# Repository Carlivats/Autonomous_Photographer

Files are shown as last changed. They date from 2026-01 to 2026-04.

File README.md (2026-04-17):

# Autonomous Photographer
*Developed by Carlos Vasquez Trochez | Supervised by Komalpreet Kaur, PhD**

*Salem State University | Computer Science Department**

The Autonomous Photographer is an intelligent, robotic camera system **designed to eliminate the compromises of taking photos during travel, outdoor activities, or public events.** By automatically recognizing subjects, analyzing scene composition, and executing motor movements, it captures visually balanced, professional-quality photographs independently.

**Built for portability and affordability,** the system allows users to step into their environment while the camera evaluates the composition, repositions itself, and takes the perfect shot.

---

## 🚀 Key Features

* **Real-Time AI Vision (YOLOv8):** Deploys OpenCV and lightweight deep learning models (YOLOv8) for continuous subject detection. Tracking logic has been custom-engineered to prioritize facial keypoints (specifically centering on the nose)
* **Autonomous Hardware Reframing:** Evaluates scene layout based on established photographic principles (like the Rule of Thirds or Centered Symmetry). The control system translates composition scores into precise pan-tilt motor commands, actively adjusting the frame in under **2 seconds per iteration**.
* **Quality Assurance Analysis:** Continuously evaluates sharpness, contrast, exposure, and motion blur. The automated rating engine discards blurry or poorly lit shots and retains only high-quality photos.
* **Highly Portable & Wireless:** Equipped with a 5V UPS Shield and batteries for continuous, untethered power. 
* **Intuitive User Interface:** A desktop-class interface built with PyQt5 that mimics an everyday camera app. Users can initiate sessions, adjust framing preferences, check live statistics, and browse the integrated gallery.

---

## 🛠️ Hardware Architecture

The physical build was designed for accessibility and reproducibility using cost-effective components. **All custom 3D-printed chassis files (.stl / LycheeSlicer files) are available in this repository!!**

* **Compute & AI Acceleration:**
  * Raspberry Pi 5
  * Hailo AI HAT+ (handles computationally expensive object-detection models)
* **Vision:**
  * Raspberry Pi AI Camera Module (IMX500)
* **Motion Control:**
  * Custom 3D-printed pan-tilt mount
  * Two precision Servo Motors
  * **PCA9685 Servo Driver:** Isolates motor power from the logic board, resolving voltage-related trembling to ensure smooth, stable camera motion.
* **Power:**
  * UPS 5V Shield + Batteries for field portability

---

## 💻 Software Stack

* **Programming Language:** Python
* **Libraries & Frameworks:** OpenCV, NumPy, PyQt5 (User Interface), RPi.GPIO (Hardware Control)
* **Machine Learning:** YOLOv8
* **3D Modeling & Printing:** Blender, LycheeSlicer
* **Project Management:** Miro, GitHub

---

## 📂 Data Storage Strategy

Captured images are saved directly to local storage alongside corresponding JSON metadata files (using the exact same basename). This sidecar metadata logs:
* Timestamps
* Sharpness & Motion Blur scores
* Exposure & Contrast ratings
* Overall Composition score
* Detected subject coordinates

---

## 🔮 Future Scope

While the current prototype successfully bridges the gap between casual photography and professional composition, future iterations will focus on:
1. **Model Compression:** Optimizing the object-detection models to run entirely on the native Raspberry Pi 5 hardware, removing the need for the Hailo AI HAT+ to further reduce hardware costs.
2. **Mobile Application:** Transitioning the UI to a dedicated mobile application to provide a more accessible wireless connection and control experience for everyday users.

---

## 📬 Contact
**Carlos Vasquez Trochez**
* Email: carlosvasqueztrochez@gmail.com
* GitHub: [Carlivats](https://github.com/Carlivats)

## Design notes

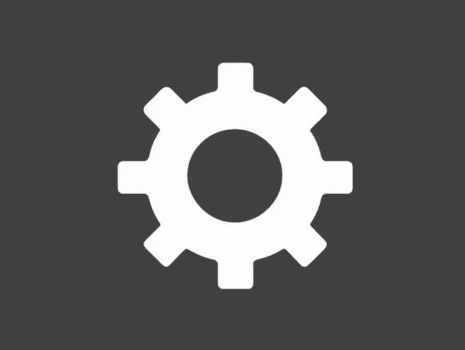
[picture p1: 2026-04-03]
src/assets/gear.png

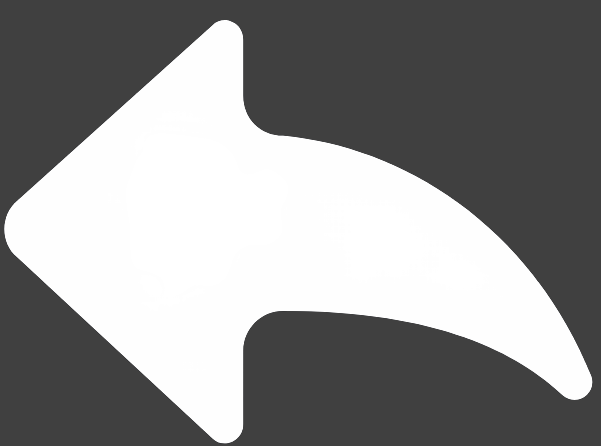
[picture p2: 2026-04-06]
src/assets/back.png

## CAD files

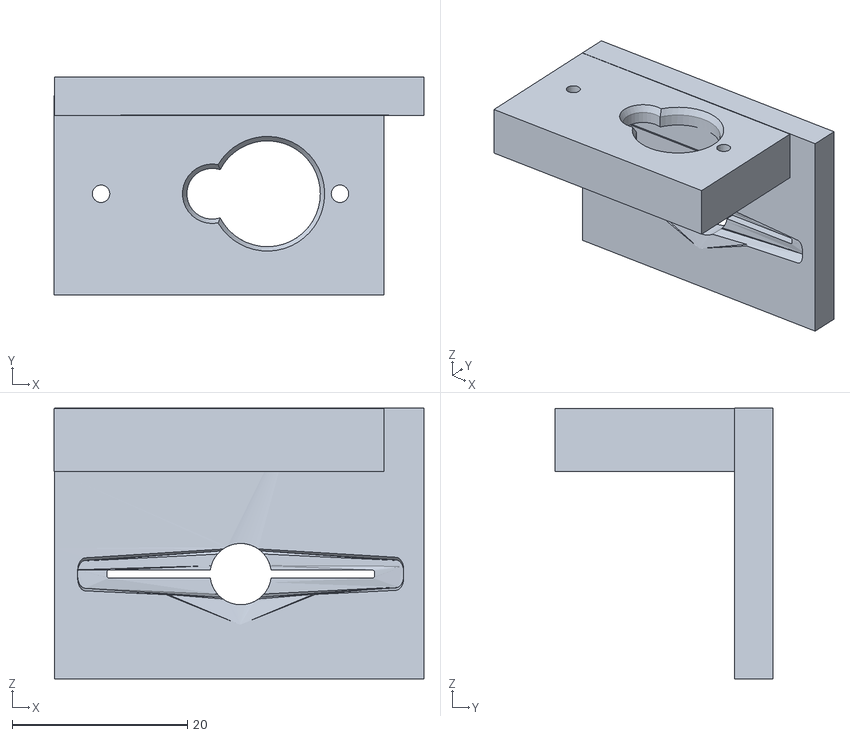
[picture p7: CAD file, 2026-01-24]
hardware/stl/ServoHolder.stl
42.3 x 24.9 x 31.0

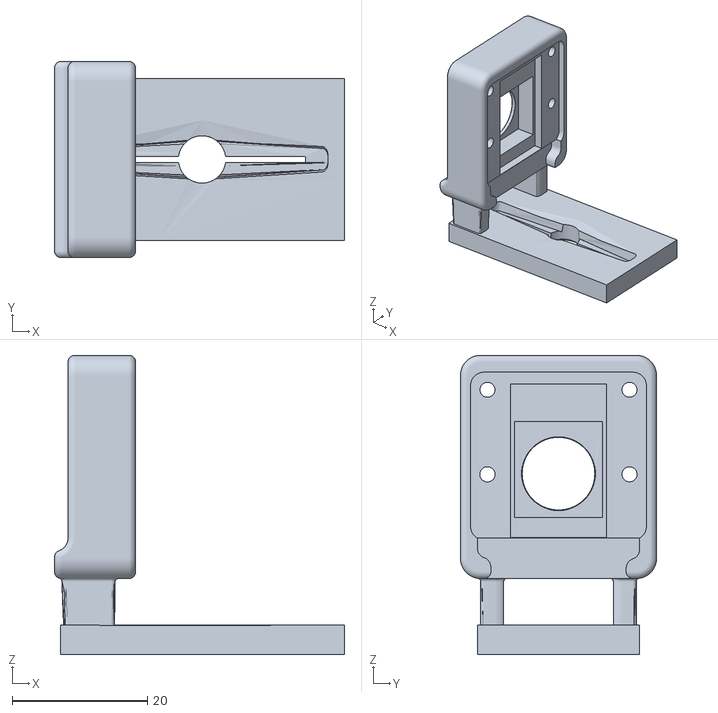
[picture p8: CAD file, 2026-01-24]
hardware/stl/CamaraHolder.stl
42.9 x 29.0 x 44.3

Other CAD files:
hardware/cad/AutonomousPhotographer_v1.00.blend
hardware/cad/AutonomousPhotographer_v1.01.blend
hardware/cad/AutonomousPhotographer_v1.02.blend
hardware/cad/AutonomousPhotographer_v1.03.blend
hardware/cad/AutonomousPhotographer_v1.04.blend

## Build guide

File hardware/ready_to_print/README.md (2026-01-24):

## 3D Printed Parts

The .pwmx files in this directory were used to fabricate prototype components for this project.
If you rather see the STL files you might find them [here](https://github.com/Carlivats/Autonomous_Photographer/tree/main/hardware/stl)

They were printed on the hardware listed below and may require adjustment to work correctly on other printers or setups.

### Printing Environment
- **Printer:** Anycubic Photon Mono X (resin printer)  
- **Resin:** Anycubic Standard Resin V2 (Gray)

### Notes & Disclaimer
- Tolerances, fit, and print quality may vary depending on printer model, resin type, and slicer settings.  
- As this project is still under active development, the designs are **subject to change** and may contain issues.
- These files are provided primarily for reference and prototyping purposes.

Fell free to to modify, re-slice, or redesign parts as needed to suit their own hardware and requirements!

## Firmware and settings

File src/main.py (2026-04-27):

# main.py
import os
import sys
import argparse
from PyQt5.QtWidgets import QApplication, QWidget, QLabel, QPushButton, QVBoxLayout, QHBoxLayout, QSizePolicy
from PyQt5.QtCore import Qt, QSize
from PyQt5.QtGui import QPixmap, QIcon

# Import our custom worker thread
from vision import CameraWorker
from session_manager import CaptureSessionManager
from gallery import GalleryUI
from settings import SettingsUI


class AutonomousPhotographerUI(QWidget):
    def __init__(self, model_path):
        super().__init__()
        self.setWindowTitle("Autonomous Photographer")
        self.resize(1024, 600)
        self.show()
        self.setStyleSheet("background-color: #16181d;")
        home_dir = os.path.expanduser("~")
        self.custom_gallery_folder = os.path.expanduser("~/Pictures/AutonomousPhotographer")

        icon_path = os.path.join(os.path.dirname(__file__), 'assets', 'gear.png')

        main_layout = QHBoxLayout()
        self.setLayout(main_layout)

        # Video Feed
        self.video_label = QLabel(self)
        self.video_label.setAlignment(Qt.AlignCenter)
        self.video_label.setStyleSheet("background-color: black; border: 2px solid #1c2024;")
        self.video_label.setSizePolicy(QSizePolicy.Ignored, QSizePolicy.Ignored)
        self.video_label.setMinimumSize(320, 240)
        main_layout.addWidget(self.video_label, stretch=3)

        # Control Panel
        control_layout = QVBoxLayout()
        
        button_style = """
            QPushButton {
                background-color: #1c2024; color: white;
                font-size: 20px; font-weight: bold;
                padding: 15px; border-radius: 8px;
            }
            QPushButton:pressed { background-color: #525a70; }
        """

        control_layout.addSpacing(20) 
        
        self.btn_settings = QPushButton("", self)
        self.btn_settings.setFixedSize(80, 80)
        
        self.btn_settings.setIcon(QIcon(icon_path))
        
        # Scale the image inside the button (40x40 leaves nice padding inside the 80x80 button)
        self.btn_settings.setIconSize(QSize(75, 75)) 
        
        self.btn_settings.setStyleSheet("""
            QPushButton {
                background-color: #1c2024; 
                border-radius: 40px; 
                border: 2px solid #525a70;
            }
            QPushButton:hover { border: 2px solid white; background-color: #2b3038; }
            QPushButton:pressed { background-color: #525a70; }
        """)
        self.btn_settings.clicked.connect(self.open_settings)

        # Center it horizontally
        settings_layout = QHBoxLayout()
        settings_layout.addStretch()
        settings_layout.addWidget(self.btn_settings)
        settings_layout.addStretch()
        
        control_layout.addLayout(settings_layout)

        self.stats_label = QLabel(self.video_label)

        control_layout.addStretch()
        
        # 1. Define the dynamic styles for the button
        self.btn_idle_style = """
            QPushButton {
                background-color: white; 
                border-radius: 40px;  /* Exactly half the width/height to make a circle */
                border: 4px solid #525a70;
            }
            QPushButton:pressed { background-color: #d0d0d0; }
        """
        
        self.btn_active_style = """
            QPushButton {
                background-color: #e74c3c; /* Red */
                border-radius: 40px;
                border: 4px solid white;
            }
            QPushButton:pressed { background-color: #c0392b; }
        """

        # 2. Create the toggle button
        self.btn_toggle = QPushButton("", self)
        self.btn_toggle.setFixedSize(80, 80)
        self.btn_toggle.setStyleSheet(self.btn_idle_style)
        self.btn_toggle.clicked.connect(self.toggle_session)

        # 3. Center the button horizontally using an internal layout
        btn_layout = QHBoxLayout()
        btn_layout.addStretch()
        btn_layout.addWidget(self.btn_toggle)
        btn_layout.addStretch()

        # Add the centered button to the main control panel
        control_layout.addLayout(btn_layout)
        
        control_layout.addStretch()
        
        # Use RGBA for the background color to set the alpha channel (transparency)
        # 166 out of 255 is roughly 65% opacity (35% transparent)
        self.stats_label.setStyleSheet("""
            background-color: rgba(28, 32, 36, 166); 
            color: #a0aabf; 
            font-size: 16px; 
            font-family: monospace;
            padding: 15px;
            border-radius: 0px;
        """)

        # Initialize with placeholder text
        self.stats_label.setText("Sharpness : N/A\nExposure  : N/A\nContrast  : N/A\nScene Blur: N/A")
        
        # 2. Position it in the top-left corner with a 15px margin
        self.stats_label.move(15, 15)
        
        # 3. Ensure it sizes itself correctly right on startup
        self.stats_label.adjustSize()

        self.btn_gallery = QPushButton("Gallery", self)
        self.btn_gallery.setStyleSheet(button_style)
        self.btn_gallery.clicked.connect(self.open_gallery)
        control_layout.addWidget(self.btn_gallery)

        self.btn_exit = QPushButton("Exit App", self)
        self.btn_exit.setStyleSheet(button_style.replace("#1c2024", "#e74c3c").replace("#525a70", "#c0392b"))
        self.btn_exit.clicked.connect(self.close_app)
        control_layout.addWidget(self.btn_exit)

        main_layout.addLayout(control_layout, stretch=1)

        # --- Initialize Session Manager ---
        self.session_manager = CaptureSessionManager(gallery_dir=self.custom_gallery_folder)
        self.session_manager.session_finished_signal.connect(self.end_session_ui)

        # --- Initialize and Start the Camera Thread ---
        self.thread = CameraWorker(model_path)
        self.thread.change_pixmap_signal.connect(self.update_image)
        self.thread.stats_signal.connect(self.update_stats_panel)
        
        self.thread.start()

    # --- UI Slots (Actions) ---
    def update_image(self, q_img_annotated, q_img_clean):
        # Save the CLEAN frame to memory so the session manager can grab it
        self.current_frame = q_img_clean.copy() 
        
        # Show the ANNOTATED frame with all the tracking lines on the UI screen
        pixmap = QPixmap.fromImage(q_img_annotated)
        scaled_pixmap = pixmap.scaled(self.video_label.size(), Qt.KeepAspectRatio, Qt.SmoothTransformation)
        self.video_label.setPixmap(scaled_pixmap)

    def toggle_session(self):
        """Toggles the autonomous tracking state and updates the button color."""
        if not self.thread.is_tracking:
            # Turn ON
            print("Starting autonomous session...")
            self.thread.is_tracking = True
            self.btn_toggle.setStyleSheet(self.btn_active_style)
            
            self.session_manager.start_session()
        else:
            # Turn OFF Manually
            self.end_session_ui()

    def end_session_ui(self):
        """Resets the UI when a session ends automatically or manually."""
        print("Stopping autonomous session...")
        self.thread.is_tracking = False
        self.session_manager.stop_session()
        self.btn_toggle.setStyleSheet(self.btn_idle_style)

    def update_stats_panel(self, stats):
        """Updates the text label whenever the vision thread emits new data."""
        sharpness = stats.get("sharpness", "N/A")
        exposure = stats.get("exposure", "N/A")
        exposure_status = stats.get("exposure_status", "N/A")
        contrast = stats.get("contrast", "N/A")
        contrast_status = stats.get("contrast_status", "N/A")
        blur = stats.get("blur", "N/A")
        blur_status = stats.get("blur_status", "N/A")
        
        display_text = (
            f"Sharpness : {sharpness}\n"
            f"Exposure  : {exposure} ({exposure_status})\n"
            f"Contrast  : {contrast} ({contrast_status})\n"
            f"Scene Blur: {blur} ({blur_status})"
        )
        self.stats_label.setText(display_text)
        
        # Add this line to force the transparent box to snap to the new text size
        self.stats_label.adjustSize()
        
        if self.thread.is_tracking and hasattr(self, 'current_frame'):
            self.session_manager.process_frame(stats, self.current_frame)

    def open_settings(self):
        print("Opening Settings...")
        # Create an instance of the Settings UI
        self.settings_window = SettingsUI()
        
        # Show the settings window
        self.settings_window.show()

    def open_gallery(self):
        print("Opening Gallery...")
        # Create an instance of the Gallery UI
        self.gallery_window = GalleryUI(gallery_dir=self.custom_gallery_folder)
        
        # Show the gallery window
        self.gallery_window.show()

    def close_app(self):
        self.thread.stop()
        self.close()

if __name__ == "__main__":
    parser = argparse.ArgumentParser()
    parser.add_argument('-m', '--model', default='/usr/share/hailo-models/yolov8s_pose_h8l_pi.hef')
    args = parser.parse_args()

    app = QApplication(sys.argv)
    window = AutonomousPhotographerUI(args.model)
    sys.exit(app.exec_())

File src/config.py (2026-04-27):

# config.py

# Camera & Display Settings
WIDTH = 1024
HEIGHT = 768
FRAME_CX = WIDTH // 2
FRAME_CY = HEIGHT // 2

# Tracking Constants
GAIN_PAN = 0.5
GAIN_TILT = 0.15
DEADZONE = 0.03
STICKINESS = 0.8
CENTER_WIDTH = 0.25

# Vertical position for Centered Symmetry (0.0 to 1.0)
# 0.5 is dead center (lots of headroom). 0.33 is the upper third line (standard portrait).
CENTER_FACE_Y = 0.33 

# X is exactly middle (0.5), Y uses our portrait offset
CENTER_TARGET = (0.5, CENTER_FACE_Y)
INTERSECTIONS = [
    (0.33, 0.33), (0.66, 0.33),
    (0.33, 0.66), (0.66, 0.66)
]

# Servo Channels
PAN_CHANNEL = 1
TILT_CHANNEL = 0

# Editable Values from Settings Menu

# Analysis Thresholds
SHARPNESS_THRESHOLD = 20.0

MAX_SAVED_PHOTOS = 5

# 75% power to the nose (accuracy) / 25% power to the box (stability)
NOSE_WEIGHT = 0.50
BOX_WEIGHT = 0.50

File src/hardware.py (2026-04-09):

# hardware.py
import numpy as np
from adafruit_servokit import ServoKit
import config

class GimbalController:
    def __init__(self):
        self.kit = ServoKit(channels=16)
        self.pan_angle = 90
        self.tilt_angle = 90
        
        # Pull servo channels from the config file
        self.pan_channel = config.PAN_CHANNEL
        self.tilt_channel = config.TILT_CHANNEL
        
        # Center the servos on startup using the configured channels
        self.kit.servo[self.pan_channel].angle = self.pan_angle
        self.kit.servo[self.tilt_channel].angle = self.tilt_angle

    def track_target(self, err_x, err_y):
        """Moves the servos based on the calculated error."""
        if abs(err_x) > config.DEADZONE:
            self.pan_angle -= (err_x * 15 * config.GAIN_PAN)
            self.pan_angle = np.clip(self.pan_angle, 0, 180)
            self.kit.servo[self.pan_channel].angle = self.pan_angle
        
        if abs(err_y) > config.DEADZONE:
            self.tilt_angle += (err_y * 15 * config.GAIN_TILT)
            self.tilt_angle = np.clip(self.tilt_angle, 0, 180)
            self.kit.servo[self.tilt_channel].angle = self.tilt_angle

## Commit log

2026-01-24 Added hardware 3D Designs
    [AutonomousPhotographer_v1.00.blend, AutonomousPhotographer_v1.01.blend, AutonomousPhotographer_v1.02.blend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]
2026-02-04 Added Object Detection to Track Sharpness
2026-02-26 Added Servo Movement for Centered Symmetry
2026-03-12 Switched from Tkinter to PyQt
2026-03-12 Added Buttons to the UI
2026-04-02 Add settings and gallery buttons to UI
2026-04-03 Stats Panel switched to Overlay
2026-04-03 Updated Start/Stop Session Button
2026-04-03 Add settings button with gear icon to UI
2026-04-04 Made Servo Channels editable on config.py
2026-04-04 Generate frame metrics inside analyzer
2026-04-09 Fixed Blur Label. Session Manager Working
    [session_manager.py]
2026-04-10 Separated frames as main and annotated to save pictures
2026-04-15 Fix rectangle drawing on annotated frame
    [vision.py]
2026-04-15 Weights for nose and box stability in config
    [config.py, vision.py]
2026-04-15 Adjust blur threshold and replace sharpness constant with config value
    [analyzer.py, config.py, vision.py]
2026-04-27 Added Trash Button
